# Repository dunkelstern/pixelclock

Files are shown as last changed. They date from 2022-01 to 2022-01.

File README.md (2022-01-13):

# Pixel clock

This is an ornamental LED clock based on the standard SK6212 programmable
LED-Strips.

You will find a KiCAD schematic for an ESP32 module based PCB in the `/kicad`
folder.

To compile you will need Platform.io.

## Images

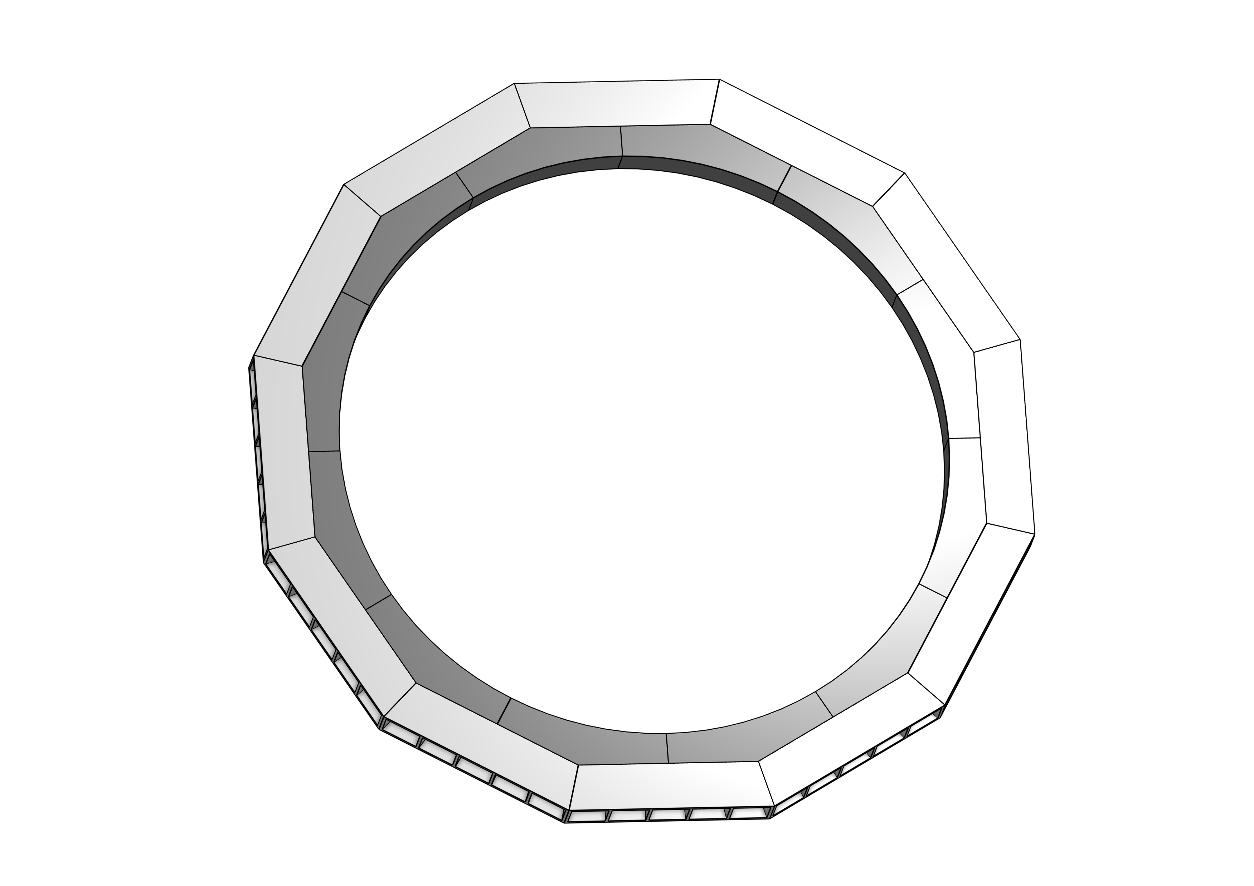
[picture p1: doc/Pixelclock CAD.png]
CAD Render of clock


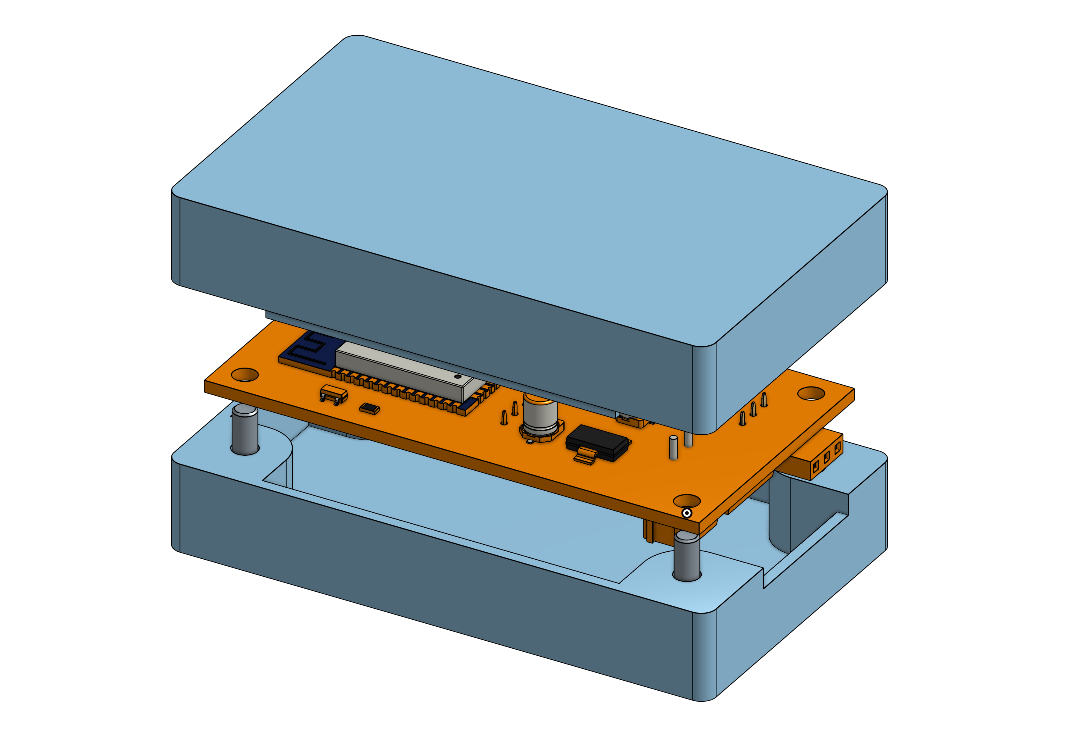
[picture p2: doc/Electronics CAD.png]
CAD Render of Electronics Housing


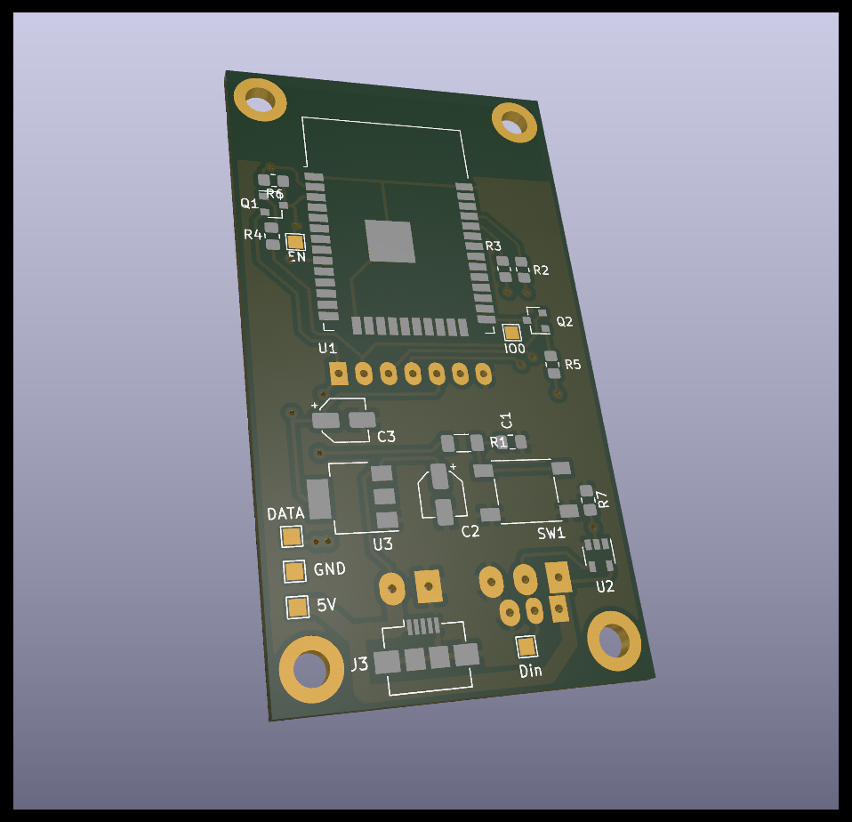
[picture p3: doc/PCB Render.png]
CAD Render of PCB


## Basic settings

For Hardware setup look into `/include/config.hpp` you can set up the following
things there:

1. `MY_NAME` is used as a MDNS Hostname as well as for MQTT topics if MQTT is enabled
2. `NEOPIXEL_IS_RGBW`, set this to 1 if you use Neopixel strips that have 4 color components (the 4. is usually White)
3. `NEOPIXEL_TYPE` see the documentation of [Neopixelbus]() for values you can use here...
4. `NEOPIXEL_PIN` the GPIO number where you connected the neopixel ring.

You have to configure the device by connecting to the AP it will open (`Pixelclock`, password is `pixelclock`) and open the website it provides at `<MY_NAME>.local`.

## TODO

- Standalone AP when no Wifi is configured
- Website that allows configuration
- JSON based API that will be used by the website
- Webserver to serve Website
- Add RTC support to PCB
- Add RTC support to code
- Documentation and pictures of finished project

## Done

- MQTT connection
- NTP update to automatically fetch time
- Saving of values to internal flash to persist settings across reboots
- Actual display of clock
- Home Assistant autoconfiguration
- Basic PCB layout
- 3D Printed parts to build clock
- 3D Printed electronics enclosure
- Topology configuration (if you have to hang the thing upside down, etc.)

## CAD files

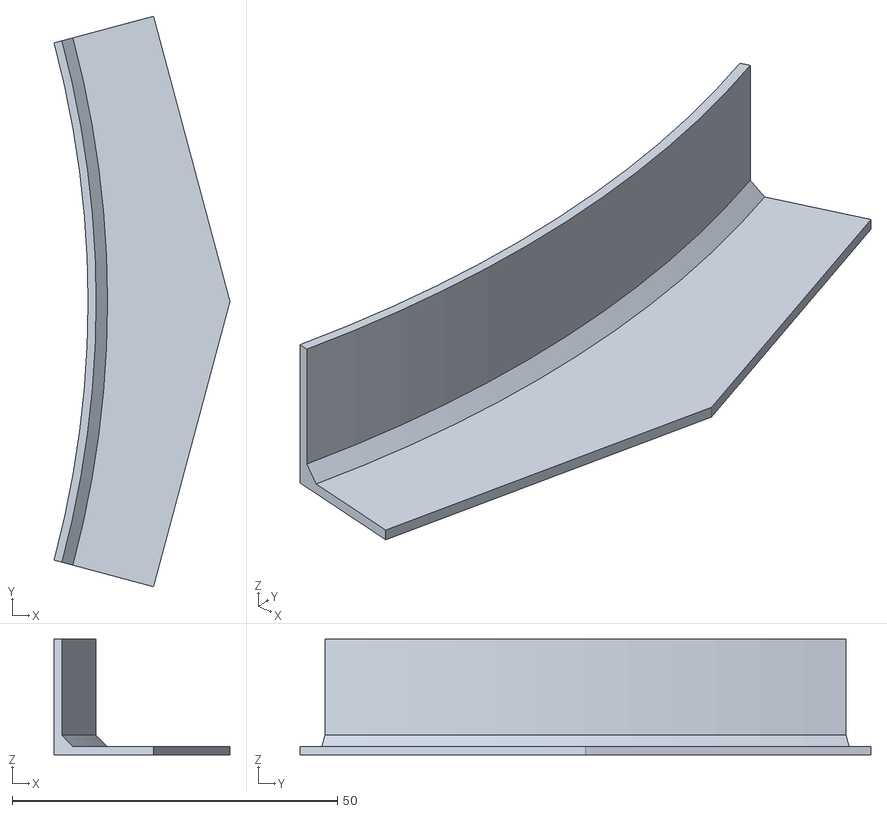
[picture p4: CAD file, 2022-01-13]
stl/Pixelclock - Cover.stl
27.0 x 87.7 x 17.8

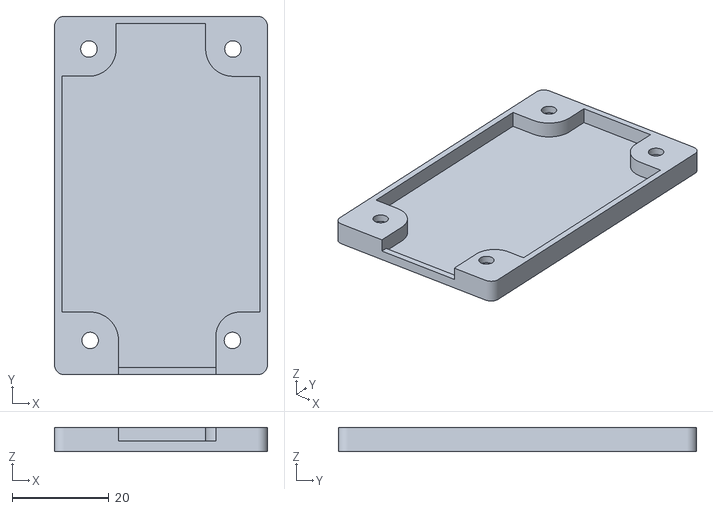
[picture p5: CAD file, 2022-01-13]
stl/Electronics Housing - Bottom (Micro USB).stl
44.0 x 74.0 x 5.00

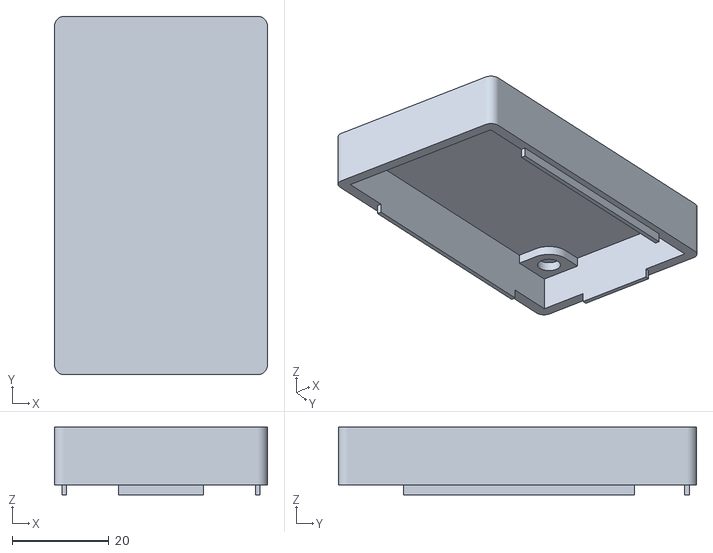
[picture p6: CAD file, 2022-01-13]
stl/Electronics Housing - Top.stl
44.0 x 74.0 x 14.0

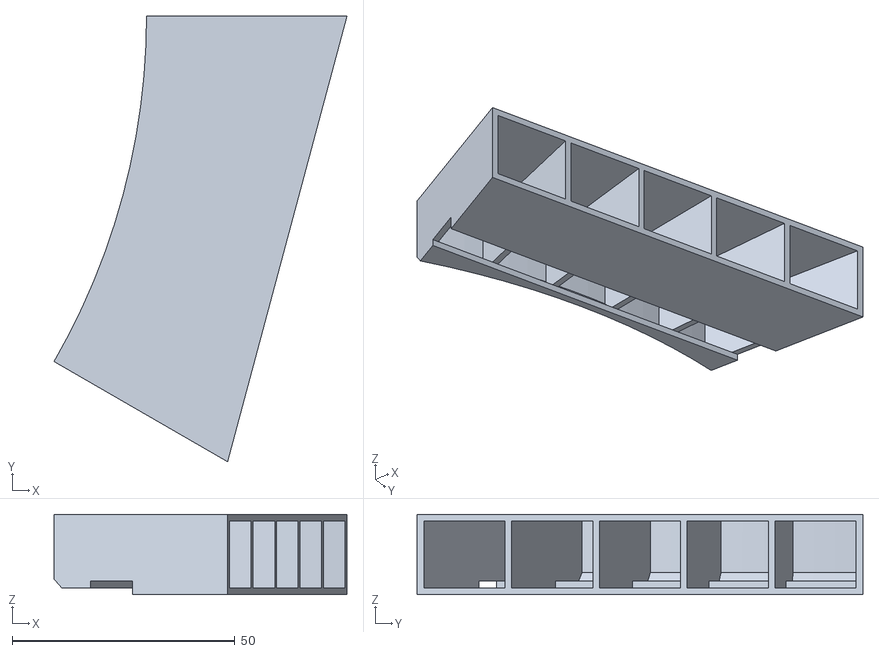
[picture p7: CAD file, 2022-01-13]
stl/Pixelclock - LightGuide.stl
65.8 x 100.0 x 18.0

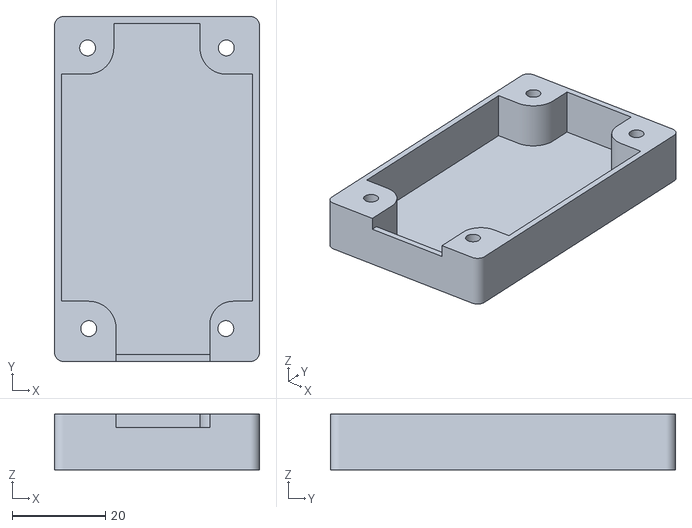
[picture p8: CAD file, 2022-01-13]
stl/Electronics Housing - Bottom (Screw Terminals).stl
44.0 x 74.0 x 12.0

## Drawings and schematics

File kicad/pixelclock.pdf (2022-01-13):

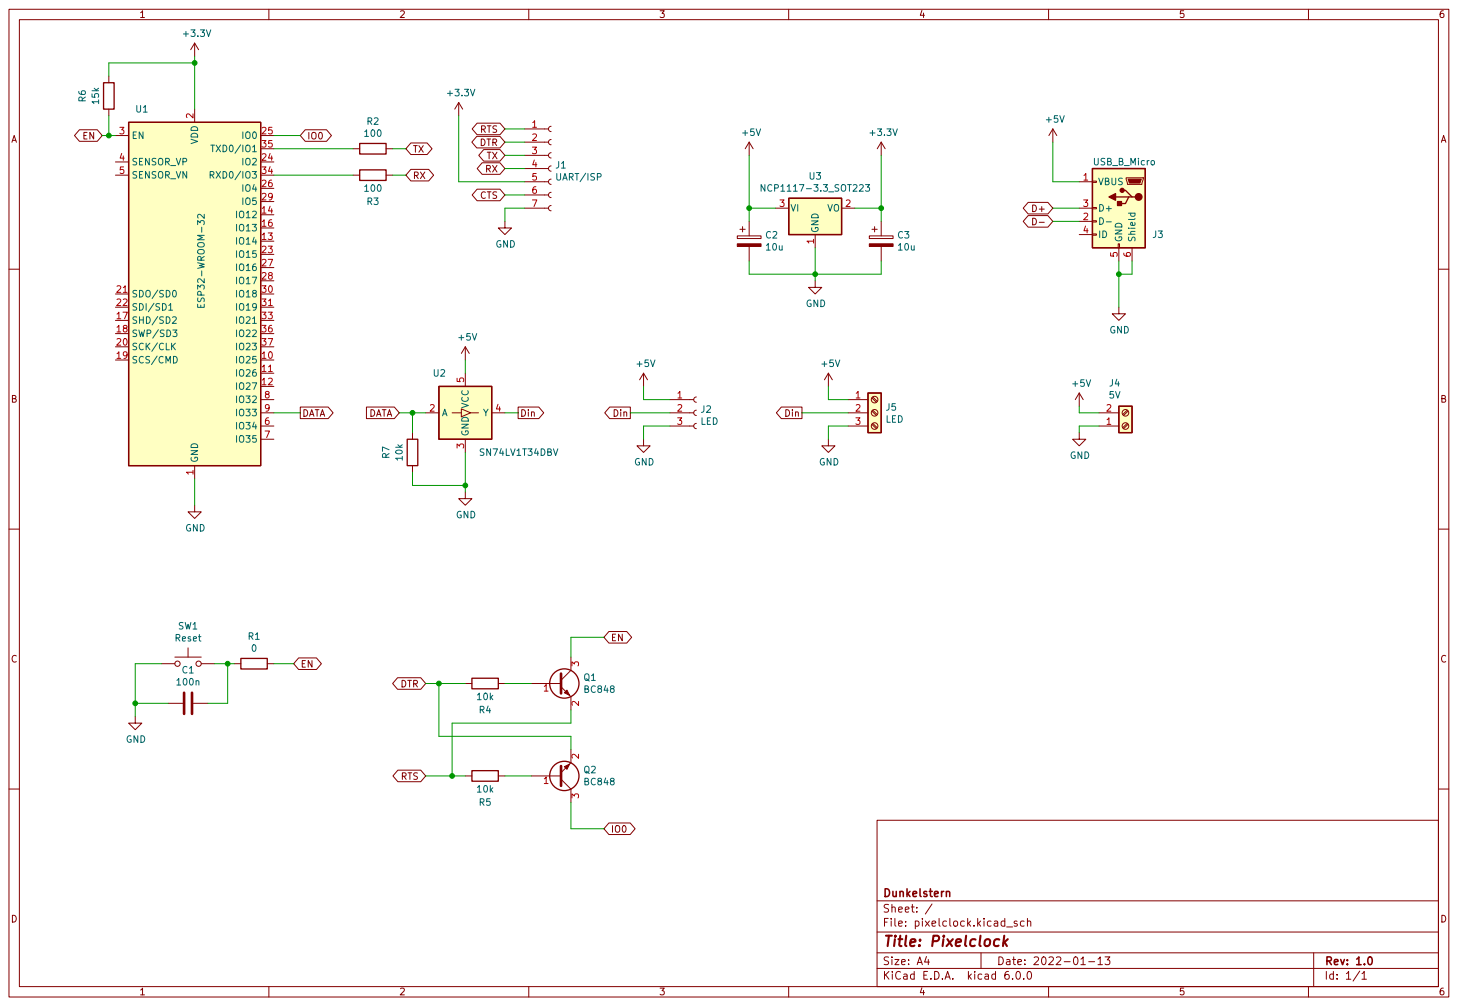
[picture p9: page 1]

2 SCK/CLK 20 SDO/SD0 21 SDI/SD1 22

1 VO 2 VI 3 U3 NCP1117-3.3_SOT223 TX DTR

File: pixelclock.kicad_sch Sheet: / Dunkelstern

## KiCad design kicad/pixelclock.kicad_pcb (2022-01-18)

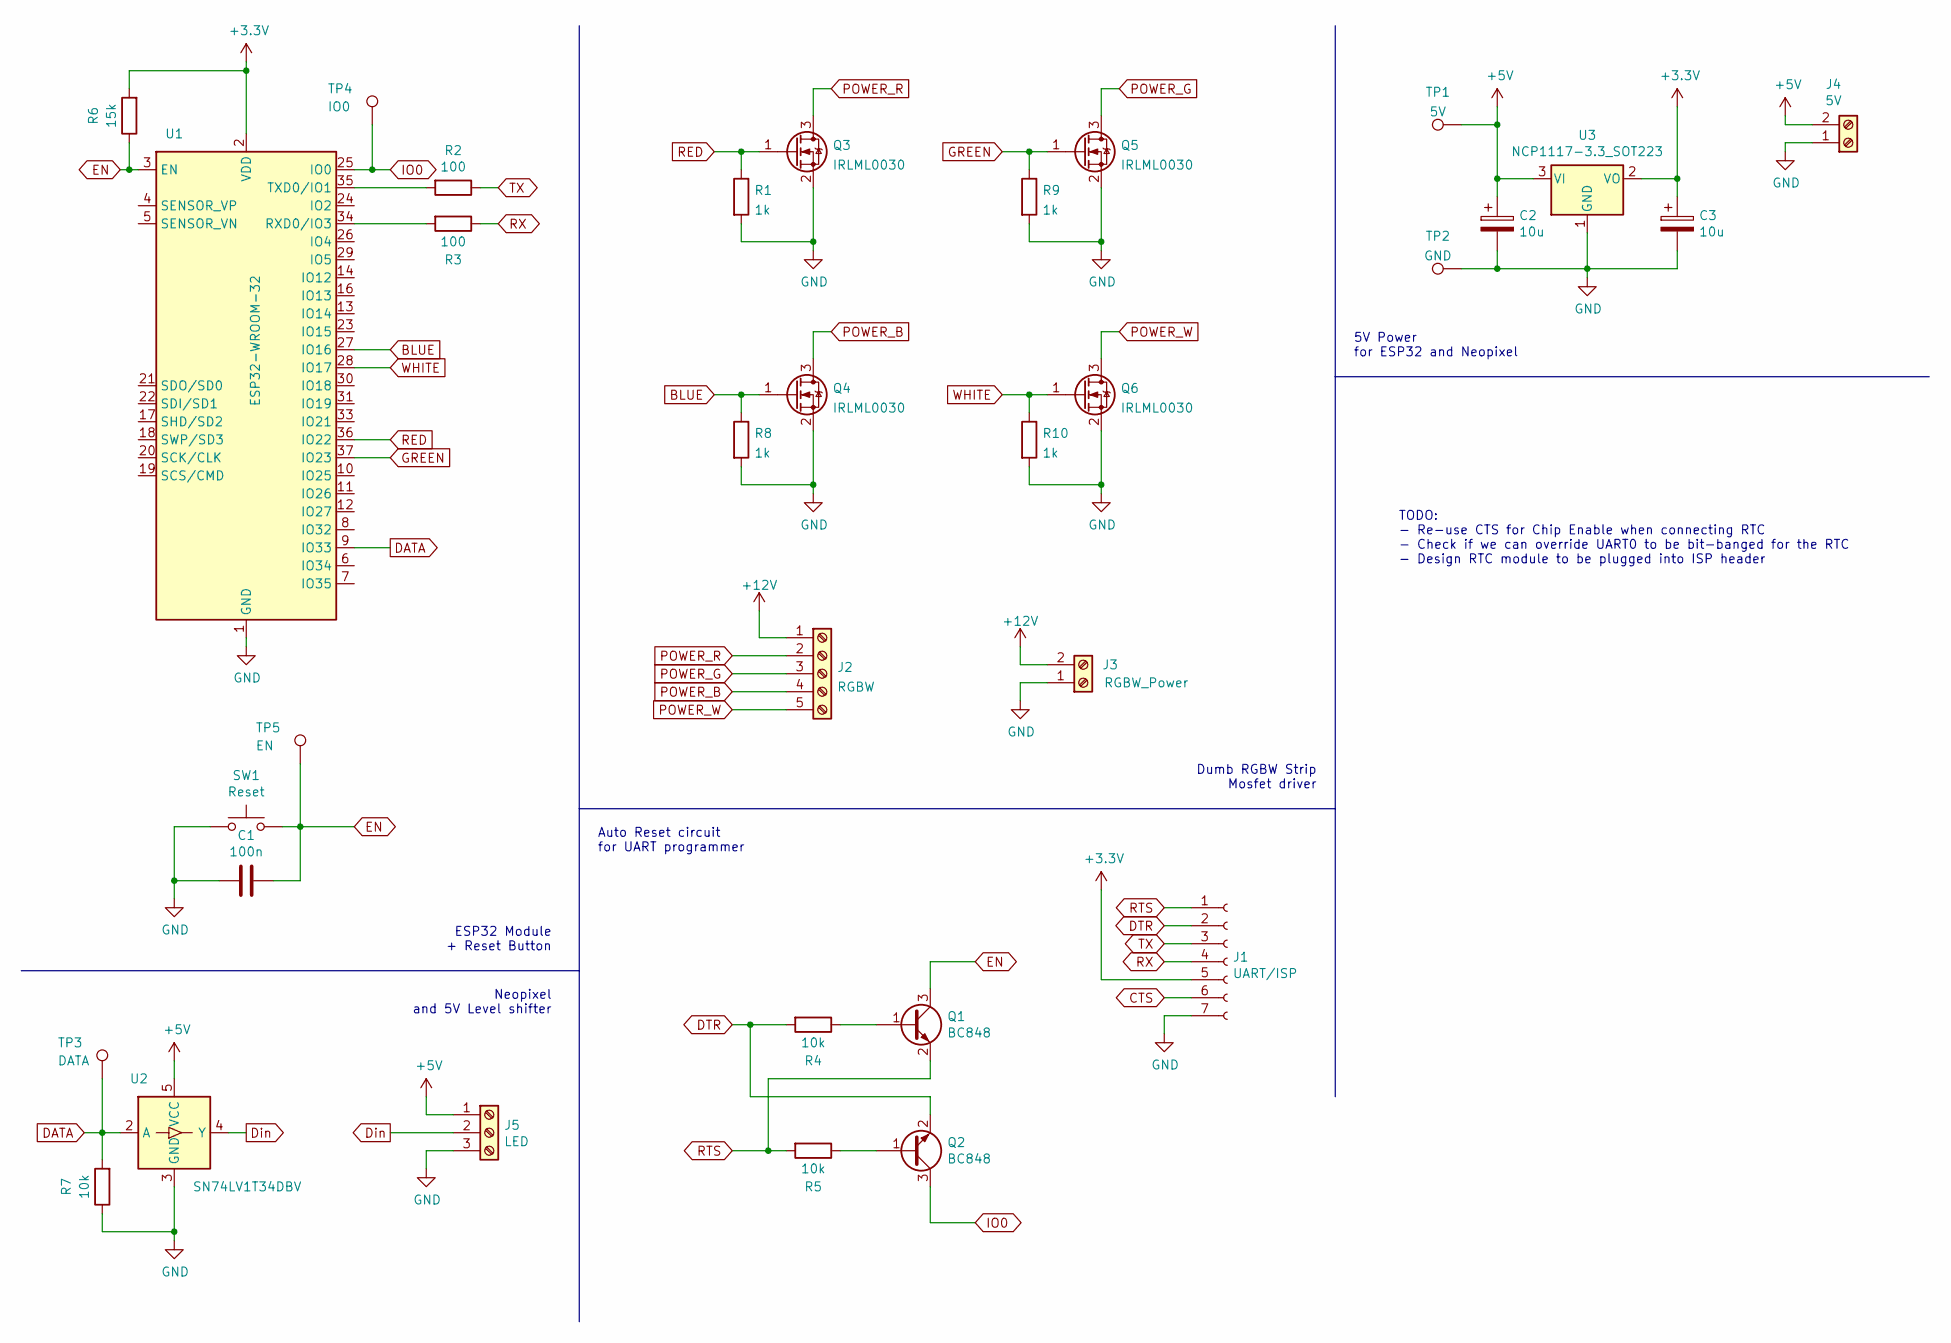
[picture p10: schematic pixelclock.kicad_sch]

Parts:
C1: 100n; C_0805_2012Metric_Pad1.18x1.45mm_HandSolder
C2, C3: 10u; CP_Elec_4x5.3
J1: UART/ISP; PinSocket_1x07_P2.54mm_Horizontal
J2: RGBW; TerminalBlock_Phoenix_PT-1,5-5-3.5-H_1x05_P3.50mm_Horizontal
J3: RGBW_Power; TerminalBlock_Phoenix_PT-1,5-2-3.5-H_1x02_P3.50mm_Horizontal
J4: 5V; TerminalBlock_Phoenix_PT-1,5-2-3.5-H_1x02_P3.50mm_Horizontal
J5: LED; TerminalBlock_Phoenix_PT-1,5-3-3.5-H_1x03_P3.50mm_Horizontal
Q1, Q2: BC848; SOT-23
Q3, Q4, Q5, Q6: IRLML0030; SOT-23
R1, R8, R9, R10: 1k; R_0805_2012Metric_Pad1.20x1.40mm_HandSolder
R2, R3: 100; R_0805_2012Metric_Pad1.20x1.40mm_HandSolder
R4, R5, R7: 10k; R_0805_2012Metric_Pad1.20x1.40mm_HandSolder
R6: 15k; R_0805_2012Metric_Pad1.20x1.40mm_HandSolder
SW1: Reset; SW_Push_1P1T_NO_6x6mm_H9.5mm
TP1: 5V; TestPoint_Pad_1.5x1.5mm
TP2: GND; TestPoint_Pad_1.5x1.5mm
TP3: DATA; TestPoint_Pad_1.5x1.5mm
TP4: IO0; TestPoint_Pad_1.5x1.5mm
TP5: EN; TestPoint_Pad_1.5x1.5mm
U1: ESP32-WROOM-32
U2: SN74LV1T34DBV; SOT-23-5
U3: NCP1117-3.3_SOT223; SOT-223-3_TabPin2

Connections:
+3V3: C3.1, J1.5, R6.2, U1.2 (VDD), U3.2 (VO)
+5V: C2.1, J4.2, J5.1, TP1.1, U2.5 (VCC), U3.3 (VI)
+12V: J2.1, J3.2
BLUE: Q4.1 (G), R8.1, U1.27 (IO16)
CTS: J1.6
DATA: R7.2, TP3.1, U1.9 (IO33), U2.2 (A)
DTR: J1.2, Q2.2 (E), R4.2
Din: J5.2, U2.4 (Y)
EN: C1.1, Q1.3 (C), R6.1, SW1.2, TP5.1, U1.3 (EN)
GND: C1.2, C2.2, C3.2, J1.7, J3.1, J4.1, J5.3, Q3.2 (S), Q4.2 (S), Q5.2 (S), Q6.2 (S), R1.2, R7.1, R8.2, R9.2, R10.2, SW1.1, TP2.1, U1.1 (GND), U1.15 (GND), U1.38 (GND), U1.39 (GND), U2.3 (GND), U3.1 (GND)
GREEN: Q5.1 (G), R9.1, U1.37 (IO23)
IO0: Q2.3 (C), TP4.1, U1.25 (IO0)
unnamed: Q1.1 (B), R4.1
unnamed: Q2.1 (B), R5.1
unnamed: R2.2, U1.35 (TXD0/IO1)
unnamed: R3.2, U1.34 (RXD0/IO3)
POWER_B: J2.4, Q4.3 (D)
POWER_G: J2.3, Q5.3 (D)
POWER_R: J2.2, Q3.3 (D)
POWER_W: J2.5, Q6.3 (D)
RED: Q3.1 (G), R1.1, U1.36 (IO22)
RTS: J1.1, Q1.2 (E), R5.2
RX: J1.4, R3.1
TX: J1.3, R2.1
WHITE: Q6.1 (G), R10.1, U1.28 (IO17)

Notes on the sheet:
ESP32 Module + Reset Button
Auto Reset circuit for UART programmer
5V Power for ESP32 and Neopixel
Dumb RGBW Strip Mosfet driver
Neopixel and 5V Level shifter
TODO: - Re-use CTS for Chip Enable when connecting RTC - Check if we can override UART0 to be bit-banged for the RTC - Design RTC module to be plugged into ISP header

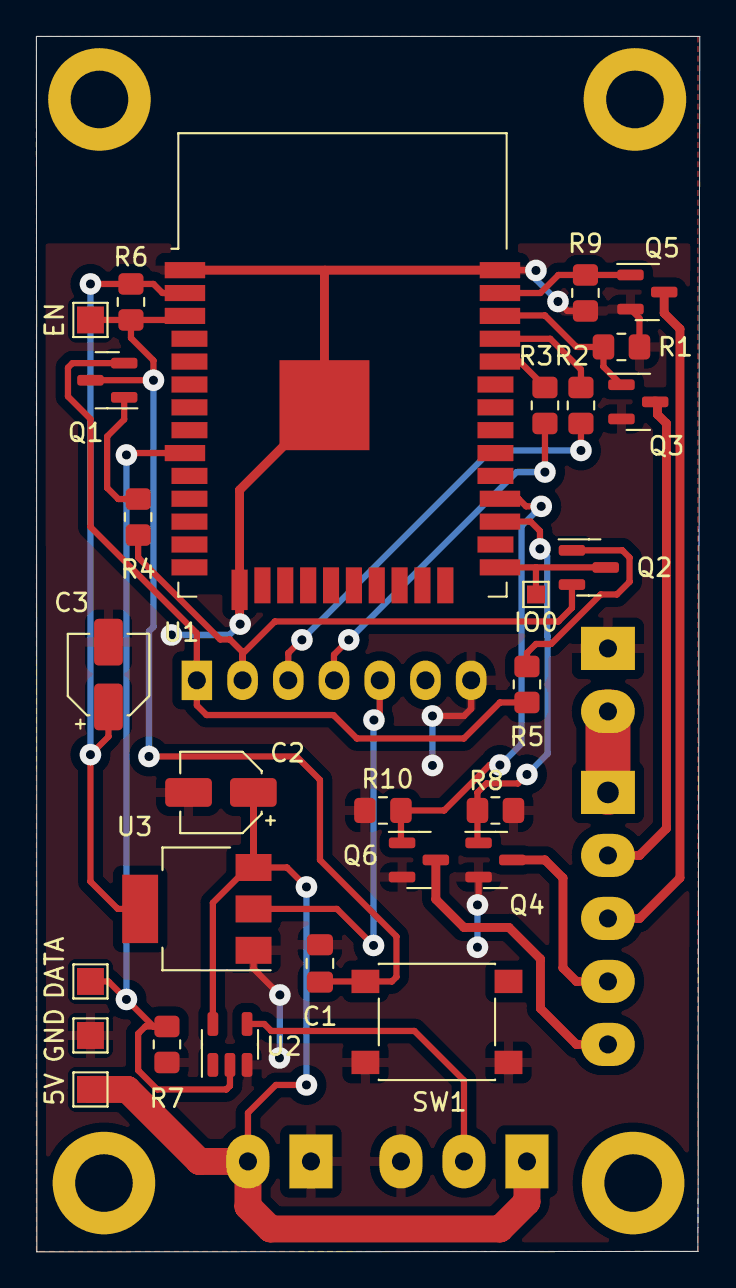
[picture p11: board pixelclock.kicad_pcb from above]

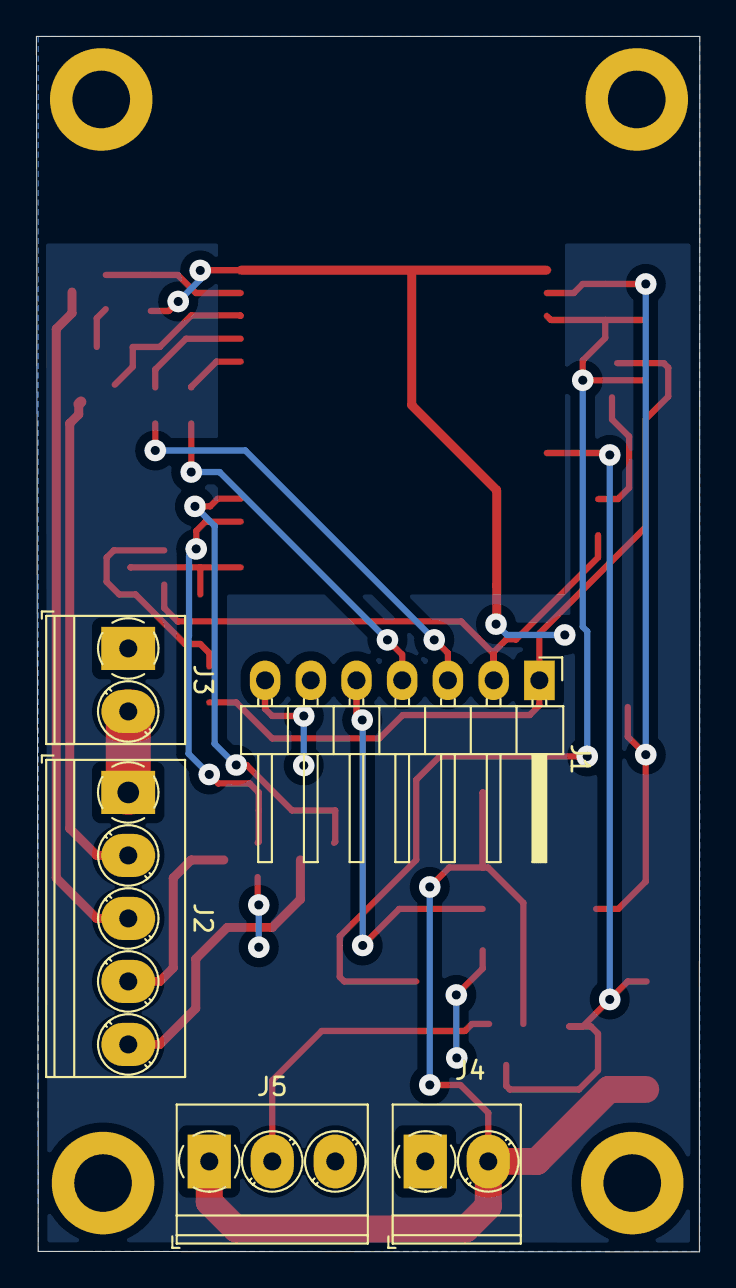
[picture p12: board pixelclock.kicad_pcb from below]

Board: 2 copper layers, 36.8 x 67.5 mm, 37 parts (5 on the bottom side), 24 nets.

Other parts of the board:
M1: MountingHole_3.2mm_M3_ISO7380_Pad
MH2, MH3, MH4: MountingHole_3.2mm_M3_ISO7380_Pad

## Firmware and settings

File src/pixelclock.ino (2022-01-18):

#include "internal.hpp"

#include "settings.hpp"
#include "wifi_service.hpp"
#include "mqtt_service.hpp"
#include "time_service.hpp"
#include "pixelclock.hpp"

#include "esp_wifi.h"

#if LED_STRIP_ENABLED
#include "rgbwled_service.hpp"
#endif

/*********************************************************
 * To change basic HW configuration look into config.hpp *
 *********************************************************/

Settings *conf;
WifiService *wifi;
MQTTService *mqtt;
TimeService *timeService;
PixelClock *pixelClock;

#if LED_STRIP_ENABLED
RGBWLedService *ledService;
#endif

void setup() {
    setCpuFrequencyMhz(240);
    esp_wifi_set_ps(WIFI_PS_NONE);
    
    Serial.begin(115200);
    conf = new Settings();
    
    conf->setDefault("color_h", Color(0, 0, 255));
    conf->setDefault("color_m", Color(0, 255, 0));
    conf->setDefault("color_s", Color(255, 0, 0));
    conf->setDefault("brightness", 255, true);
    conf->setDefault("enabled", 1, true);
    conf->setDefault("tz_offset_h", 0);
    conf->setDefault("tz_offset_m", 0);
    conf->setDefault("topology", 0);
    
    conf->setDefault("wifi_ssid", "");
    conf->setDefault("wifi_pass", "");
    
    conf->setDefault("ntp_server", "time.nist.gov");
    conf->setDefault("ntp_enabled", 1);
    
    conf->setDefault("mqtt_server", "10.0.0.2");
    conf->setDefault("mqtt_port", 1883);
    conf->setDefault("mqtt_user", "pixelclock");
    conf->setDefault("mqtt_pass", "pixelclock");
    conf->setDefault("mqtt_hass", 1);
    conf->setDefault("mqtt_enabled", 1);
    
    
    wifi = new WifiService(conf, MY_NAME);
    mqtt = new MQTTService(conf, MY_NAME);
    timeService = new TimeService(conf);
    pixelClock = new PixelClock(conf, timeService);
#if LED_STRIP_ENABLED
    conf->setDefault("s_color", Color(32, 32, 32));
    conf->setDefault("s_brightness", 255, true);
    conf->setDefault("s_enabled", 1, true);

    ledService = new RGBWLedService(conf);
#endif
}

void loop() {
    timeService->loop();
    mqtt->loop();
    pixelClock->loop();
#if LED_STRIP_ENABLED 
    ledService->loop();
#endif
    delay(33);
}

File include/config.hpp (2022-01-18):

#ifndef config_hpp__included
#define config_hpp__included

/*
 * Basic configuration
 */

// this is the hostname as well as the MQTT topic (if enabled)
#define MY_NAME "pixelclock1"

// define this to 1 if you're using RGBW LED strips, or to 0 if not
#define NEOPIXEL_IS_RGBW 1

// define the type of LEDs you use for the pixel ring 
#define NEOPIXEL_TYPE NeoSk6812Method

// the GPIO pin where you connected the LEDs
#define NEOPIXEL_PIN 33

// RGBW Strip with Mosfet control
#define LED_STRIP_ENABLED 1
#define RED_PIN 23
#define GREEN_PIN 22
#define BLUE_PIN 16
#define WHITE_PIN 17

#define RED_CORRECTION 1.0
#define GREEN_CORRECTION 0.75
#define BLUE_CORRECTION 0.25
#define WHITE_CORRECTION 0.7

#endif /* config_hpp__included */

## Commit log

2022-01-13 Kicad PCB files
    [pixelclock.kicad_pcb, pixelclock.sch]
2022-01-13 Arduino based ESP32 code
2022-01-13 Add STL files for 3D Printing
    [Electronics Housing - Bottom (Micro USB).stl, Electronics Housing - Bottom (Screw Terminals).stl, Electronics Housing - Top.stl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]
2022-01-13 Add Pictures and Schematic PDF
2022-01-13 Update to KiCad 6
    [pixelclock.kicad_pcb, pixelclock.kicad_sch]
2022-01-18 Update pixelclock board to support additional RGBW LED strip (dumb single color LED strip)
    [pixelclock.kicad_pcb, pixelclock.kicad_sch]
2022-01-18 Add software support for LED Strip driver circuitry
2022-01-18 Workaround for Bug in ESP Libs: Disable Wifi powersaving
    [pixelclock.ino]
